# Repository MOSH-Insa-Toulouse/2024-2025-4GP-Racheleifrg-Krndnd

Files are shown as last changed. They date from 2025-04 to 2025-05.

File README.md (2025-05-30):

# 2024-2025-4GP-Racheleifrg-Krndnd

# Graphite-based sensor project

**Students**: Rachele Iffrig, Karine Dandy

Département Génie Physique

INSA Toulouse

## Project Description

The aim of this project is to determine the main characteristics of a low-tech strain sensor, as introduced in the paper “Pencil Drawn Strain Gauges and Chemiresistors on Paper”  by Cheng-Wei Lin, Zhibo Zhao, Jaemyung Kim & Jiaxing Huang, published on Nature in 2014, and to compare them with those of an industrial flex sensor. To do so, both sensors are managed by an Arduino Uno board. On this board we also have an OLED screen in order to display the data, and we navigate through the menus using a rotary encoder. The data are sent to an Android application via a Bluetooth® module.<br> <br>
You can recreate this project from scratch, as we have provided everything — from the PCB design using KiCad, the Arduino code, and the Android app, to the test bench setup used to compare both sensors and create the graphite sensor’s datasheet. 

## Content

In this GitHub repository you will find independent folders for each part of our project.

1) **KiCad**: The KiCad folder contains our project (KiCad-Shield-Uno-FlexSensor) and all the libraries we created and used. It is ready to use, you will only need to download KiCad on your laptop. 
   
2) **Arduino code**: The Arduino folder contains 2 different codes: 
     *code_Flex_OR_graphite_datas_sent_via_bluetooth.ino* and *code_Flex_AND_graphite_datas_sent_via_bluetooth*. Both codes calculate the resistance of the industrial strain gauge sensor as well as the graphite-based one, and are using the rotary encoder to navigate through the different menus displayed on the OLED screen. The difference between the two codes comes with what data we are sending via Bluetooth®. In the first code, at the beginning, the user chooses which sensor’s information they want to plot in the app. The second code sends data from both sensors simultaneously: both resistances are plotted, but with less precision. 
   
3) **Android App**: The Android App folder contains all the information concerning the two apps, made with MIT App Inventor, that are receiving all the data sent via Bluetooth®. With these apps, compatible with Android, you can either plot the resistances of both the flex and graphite sensors simultaneously, or choose to plot only one of them, depending on the code you chose.      

4) **Bench test**: The Bench test folder contains pictures of our graphite-based sensor, and the bench test used.

5) **Results graphite based sensor flex_sensor**: All the results obtained and presented in the sensor's datasheet can be found on the Excel file "Results_graphite-based_sensor_and_flex_sensor". All the calculations made to obtain the relative resistance variation and the deformations are also included in this Excel file. 
   
6) **Sensor project presentation**: The Sensor project presentation folder contains a PowerPoint in which we explain the different steps of our project, the difficulties we faced and the results we obtained.

7) **Datasheet**: The datasheet folder contains the datasheet of our graphite-based sensor. This document describes the main features of the graphite-based sensor, its working principle, its working conditions, and presents the results of the comparison between the flex sensor and graphite-based one. This graphite-based sensor can measure deformations up to 0.006, at room temperature. Higher deformations can break the graphite sensor. 

We found that the hardest pencil (H) was the most sensitive. The same conclusion was also reached by Wei et al. Measurement errors may
have influenced our results, or we may have omitted other unknown factors. Nevertheless, a potential
application for this technology can be observed when using hard pencils. With further material and
experimental modifications, our handmade graphite sensor could be optimized.
 
## Physic behind the low tech strain gauges

This graphite-based sensor works similarly to a strain gauge and can detect mechanical deformations under tension or compression. 
It can measure resistances of the order of the giga-ohm. The working principle relies on the relationship between the average nanoparticle distance and the resistance. 
Due to the granular property of the graphite, under tension, the layer stretches, increasing the distance between the nanoparticles (Figure 1). 
According to percolation theory, the material’s conductivity decreases, while its resistance increases. 
In compression, the distance between the nanoparticles is reduced, and the resistance decreases as more electrical paths are present.

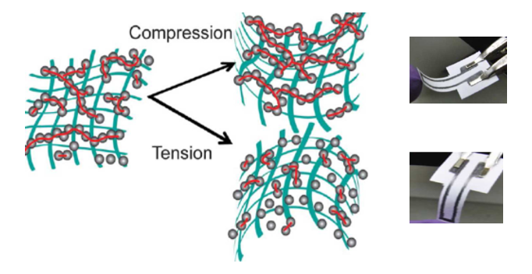
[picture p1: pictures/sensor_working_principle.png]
Imagen1


Figure 1 – Working principle of the graphite-based sensor in compression and tension. Extracted from
“Pencil Drawn Strain Gauges and Chemiresistors on Paper”, by Cheng-Wei et al.

## Necessary components to carry out this project

* 1 graphite-based paper sensor
* 1 flex sensor
* 1 LTC1050 operational amplifier
* 1 MCP41050 digital potentiometer
* 1 KY-040 rotary encoder
* 1 Arduino UNO
* 1 OLED screen
* 1 HC-05 Bluetooth® module
* Resistances: 1kΩ, 10kΩ, 100kΩ, 100kΩ
* Capacitors: 100nF, 100nF, 1µF
* For the test bench: 1 round glass, 1 glue stick, 1 tape, 1 toothpaste cap, 1 liquid correction fluid (Tipp-Ex)

<figure>
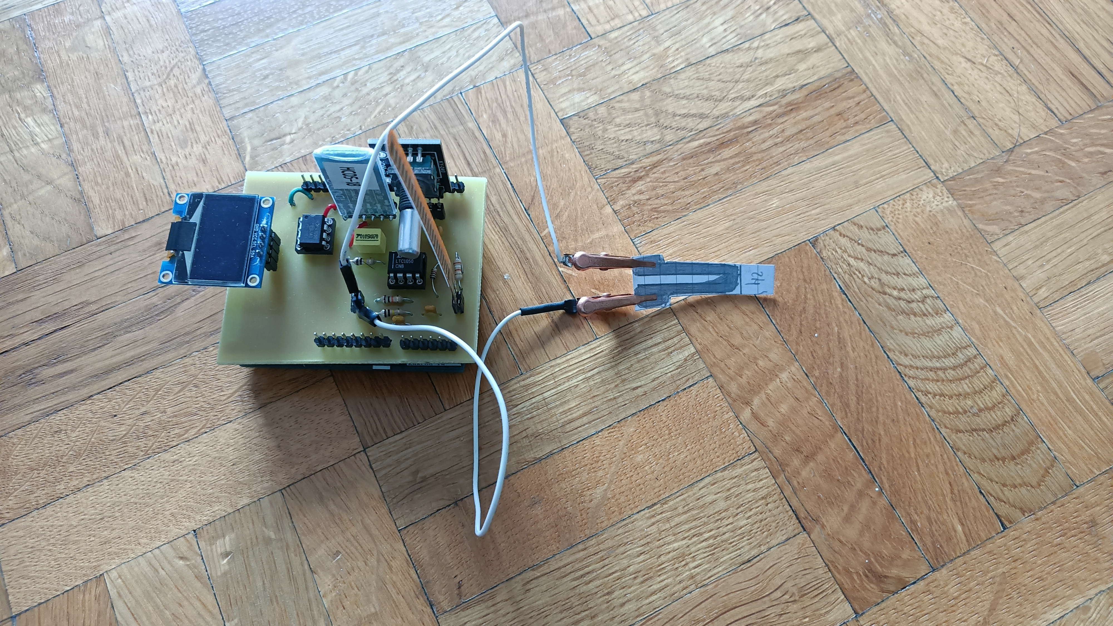
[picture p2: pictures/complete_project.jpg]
complete_project
  
  <figcaption>Figure 2 - Image of the complete project.</figcaption>
</figure>

## How to use

The first step is to create the electrical amplifier circuit and the footprint of the PCB on KiCad. Our complete KiCad project and all the libraries used can be found in the KiCad folder.  

The second step is to order or fabricate the PCB and mount it on an Arduino UNO board. 

By using similar features as our graphite-based sensor (Figure 3), and our Arduino code (available in the Arduino code folder), it is possible to measure a resistance for a given deformation. 

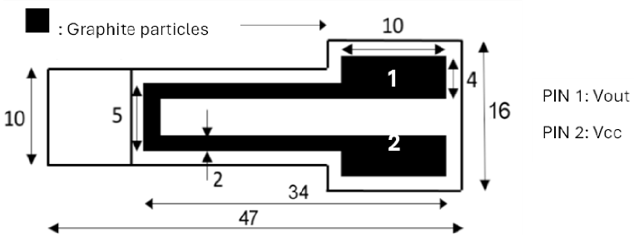
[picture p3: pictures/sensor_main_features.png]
Imagen3


Figure 3 – Representation of our graphite-based sensor. The units are in mm. Extracted from the work
of Paul Besnard and Niels Brun, available on GitHub.

This graphite-based sensor can measure deformations up to 0.006, at room temperature. This sensor can
be made with other paper and graphite pencils to improve sensitivity. We highly recommend
the use of thin papers and harder graphite pencils. 

### Project Assembly

1) Create the PCB using the file *KiCad-Shield-Uno-FlexSensor.kicad_pro* (KiCad/KiCad-Shield-Uno-FlexSensor.kicad_pro) found in the **KiCad** folder. NB: you can also use a breadboard and follow the schematic from the following file: *KiCad-Shield-Uno-FlexSensor.kicad_sch* (KiCad/KiCad-Shield-Uno-FlexSensor.kicad_sch)
2) Solder the components following the PCB and schematic that can be found in the same **KiCad** folder.
3) Connect the PCB to the Arduino, and then connect the Arduino to a PC via USB.
4) Choose one of the two codes from the **Arduino** folder based on your needs.      
5) Once the program is open in the Arduino IDE, select **Arduino Uno** as the board.
6) Run the code.
7) If you chose: *code_Felex_OR_graphite_datas_sent_via_bluetooth.ino* select the data you want to plot on the app, following the instructions that appear on the Serial.

### OLED's Menus
When you upload the code to the Arduino, the OLED screen lights up. On the OLED display, you can access **three different menus**:

1. **Potentiometer Selection Menu**  
   Allows you to choose between **four different potentiometer values**.

2. **Flex Sensor Data Menu**  
   Displays real-time data from the **flex sensor**.

3. **Graphite Sensor Data Menu**  
   Displays real-time data from the **graphite sensor**.<br> <br>
To switch between menus, press the rotary encoder. Inside each menu, rotate the encoder to scroll through the available options. To select an option (if applicable), press the rotary encoder's switch.

### Android App
1. **Pair your smartphone with the HC-05 Bluetooth module.** If a code is requested, enter **0000** or **1234**.

2. **Download the `.exe` file to your smartphone** by scanning the **QR code** in the folder of the Android App.

3. **Open the application**
4. **Grant the necessary permissions** to the application so it can detect Bluetooth® devices connected to your Android.This can be done via your phone’s **Bluetooth® or app settings**.

5.  **Click on the Bluetooth® button**.

6. **Select the HC-05 module** from the list of available devices.

7. **Select the potentiometer value** that you previously chose using the **OLED menu** on the Arduino.

8. **If you are using the Flex or Graph app**,select the resistance value you chose at the beginning of the program from the **drop-down menu**.

9. **Start data acquisition** by pressing the **Start** button.

10. **Stop data acquisition** by pressing the **Stop** button.

<figure>
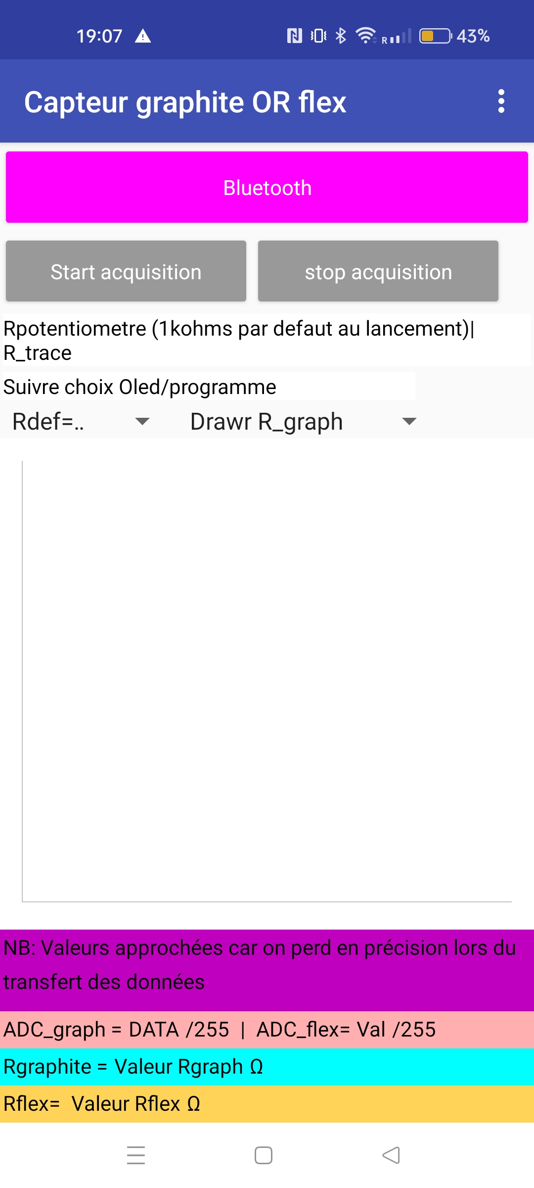
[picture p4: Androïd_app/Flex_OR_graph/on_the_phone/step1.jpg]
app
  
  <figcaption>Figure 4 - Image of the screen when we open the app</figcaption>
</figure>

### Test Bench

To test and compare our graphite-based sensor to a commercial sensor (the flex sensor), we used five objects with different diameters. We then fabricated and tested our graphite-based sensor using three different types of pencils: 2B, H, and HB.   

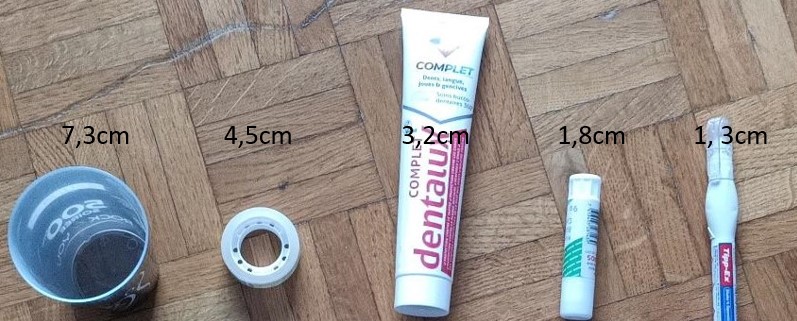
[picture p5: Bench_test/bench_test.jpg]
Imagen5


Figure 5 – Photograph of the objects used with the corresponding diameters during the bench test.

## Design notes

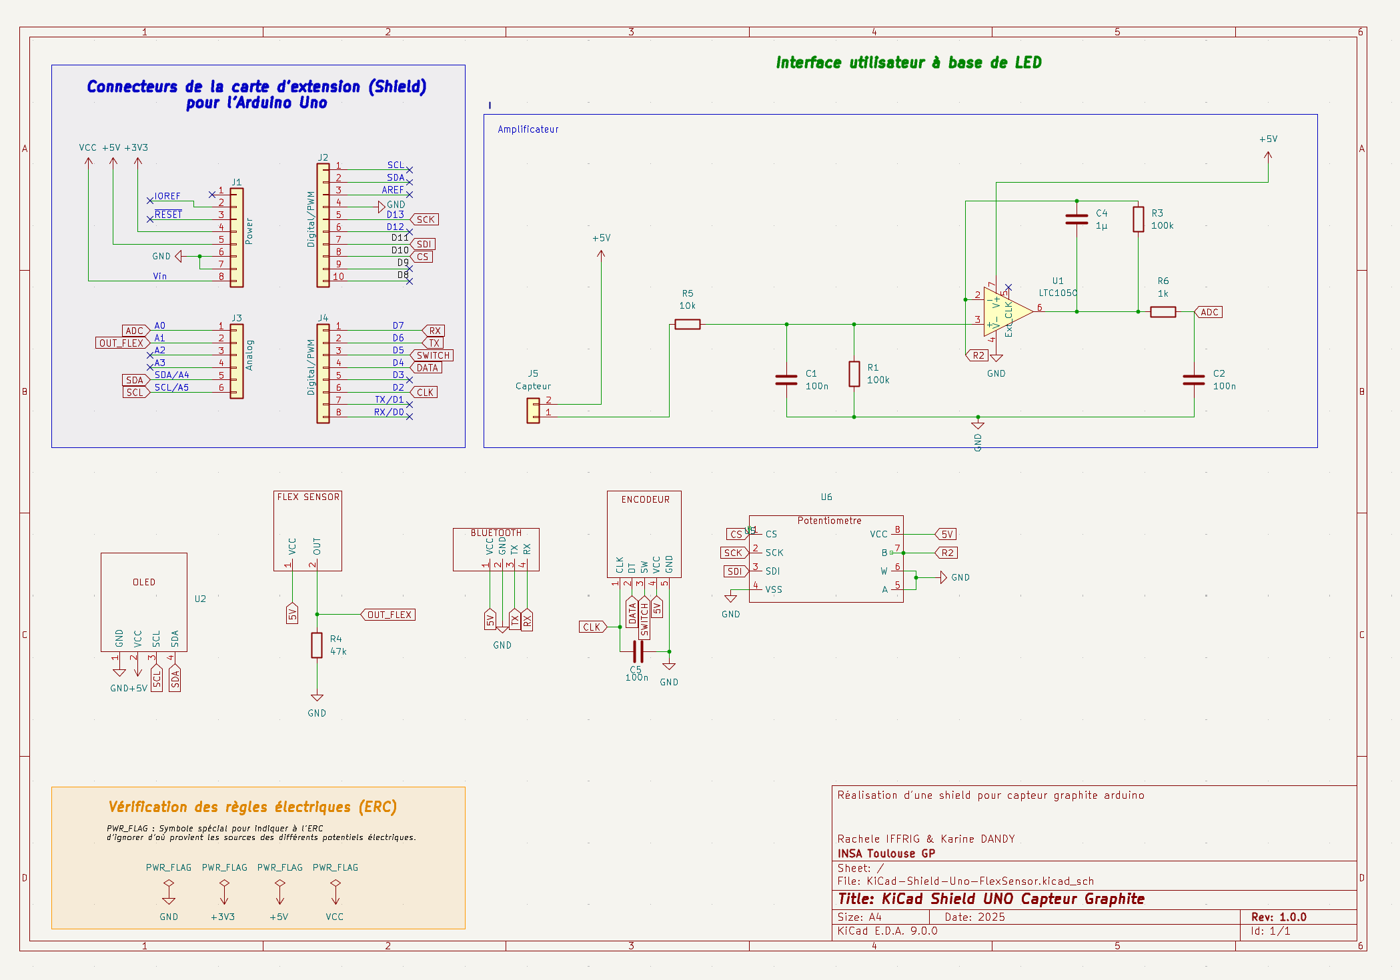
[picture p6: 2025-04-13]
pictures/schematic.png

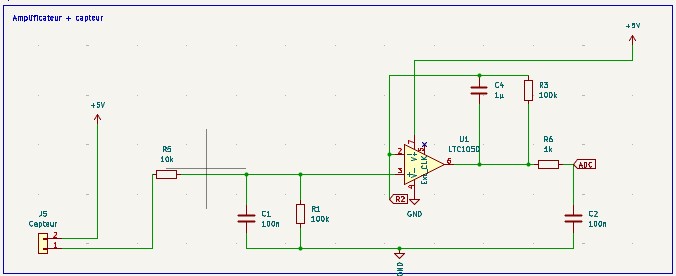
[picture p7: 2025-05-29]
KiCad/PCB_KiCad_models/Amplifier_schematic.jpg

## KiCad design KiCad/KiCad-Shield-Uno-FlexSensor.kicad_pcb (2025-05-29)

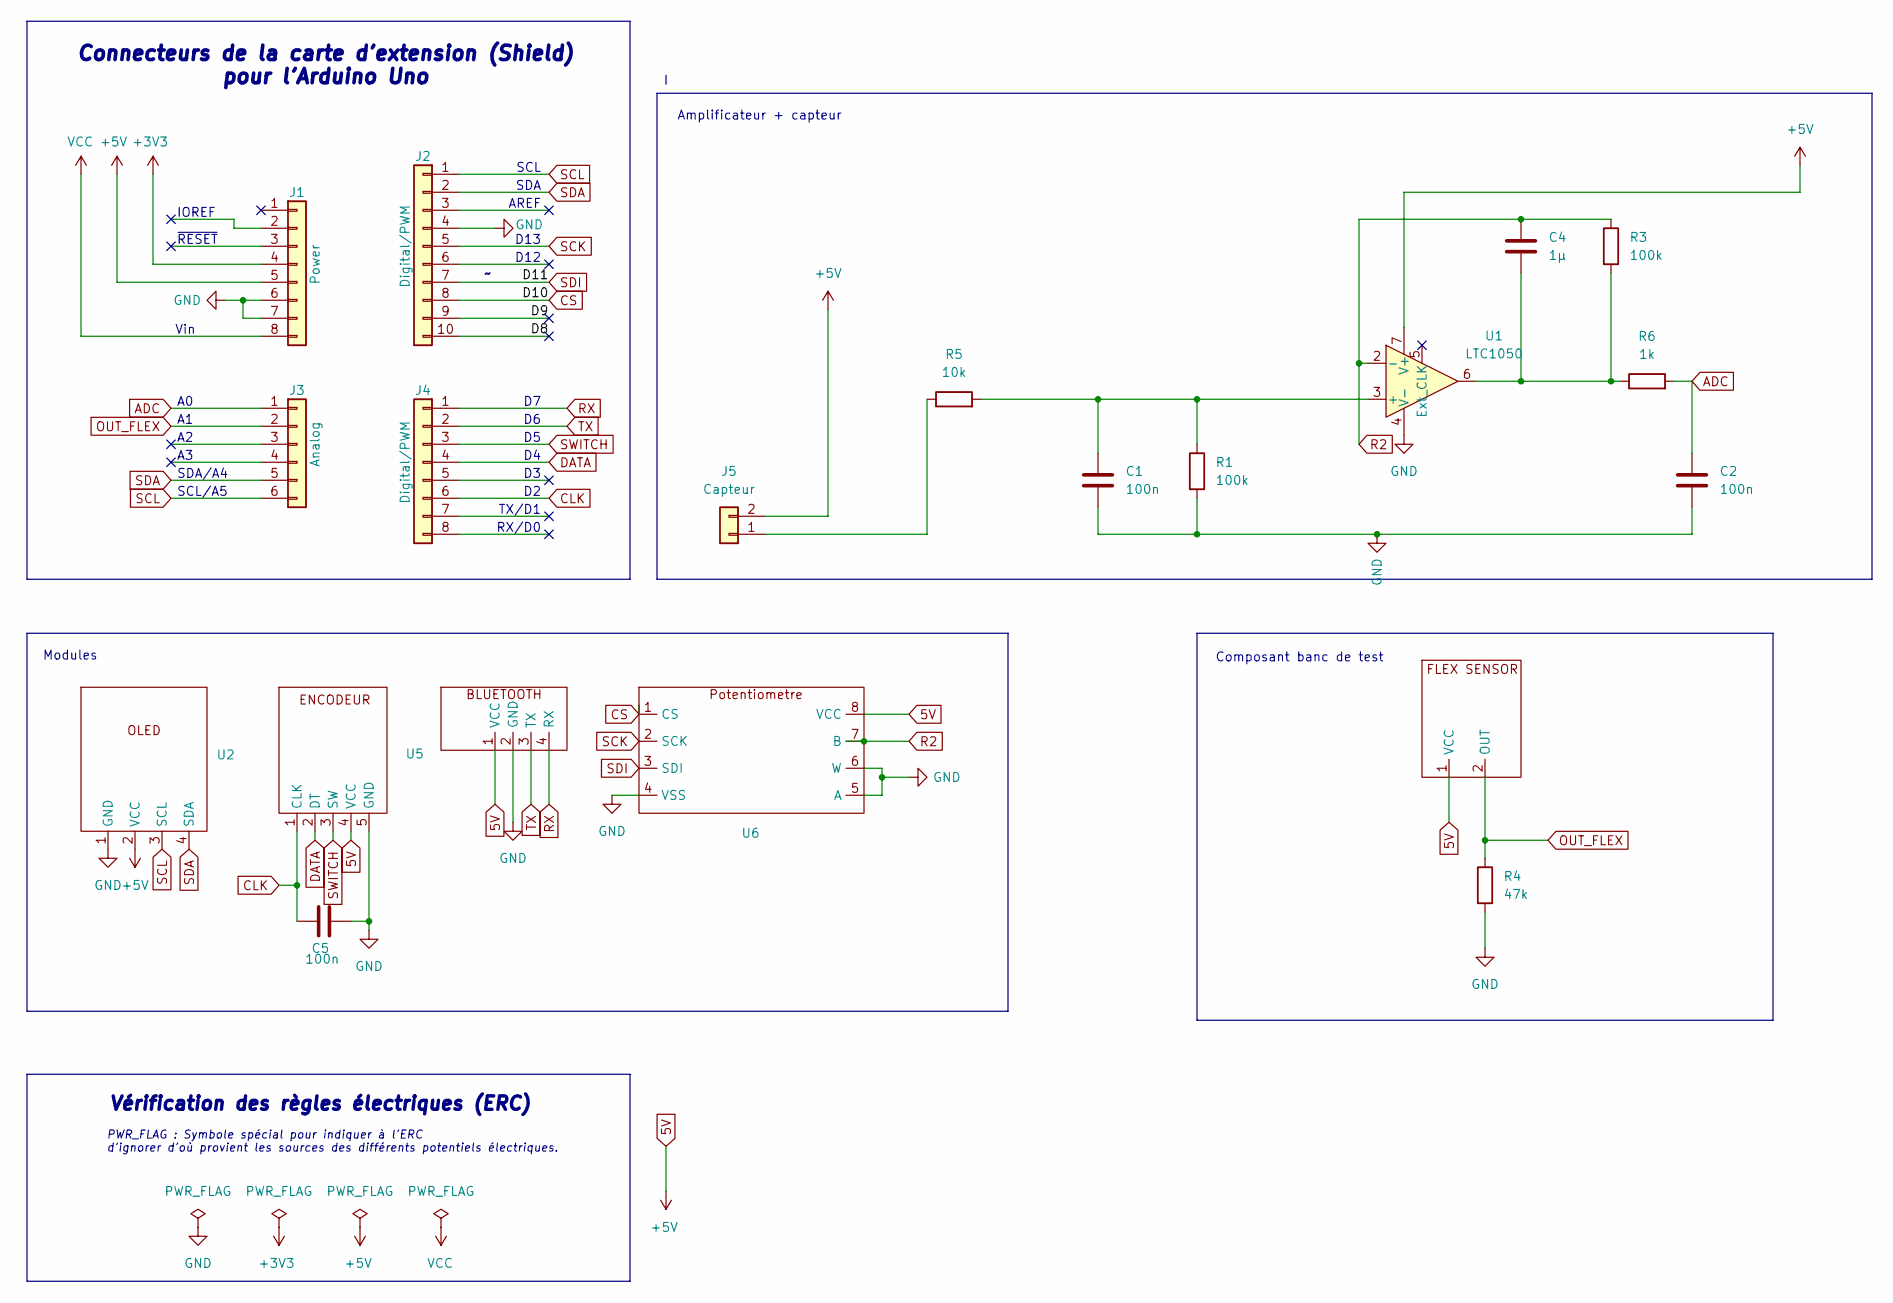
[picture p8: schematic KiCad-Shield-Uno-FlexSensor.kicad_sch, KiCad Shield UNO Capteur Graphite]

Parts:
C1: 100n; C_Disc_D5.0mm_W2.5mm_P5.00mm
C2: 100n; C_Disc_D4.7mm_W2.5mm_P5.00mm
C4: 1µ; C_Rect_L7.0mm_W4.5mm_P5.00mm
C5: 100n; C_Disc_D6.0mm_W2.5mm_P5.00mm
J1: Power; PinSocket_1x08_P2.54mm_Vertical
J2: Digital/PWM; PinSocket_1x10_P2.54mm_Vertical
J3: Analog; PinSocket_1x06_P2.54mm_Vertical
J4: Digital/PWM; PinSocket_1x08_P2.54mm_Vertical
J5: Capteur; PinSocket_1x02_P2.54mm_Vertical
R1, R3: 100k; R_Axial_DIN0207_L6.3mm_D2.5mm_P10.16mm_Horizontal
R4: 47k; R_Axial_DIN0207_L6.3mm_D2.5mm_P5.08mm_Vertical
R5: 10k; R_Axial_DIN0207_L6.3mm_D2.5mm_P10.16mm_Horizontal
R6: 1k; R_Axial_DIN0207_L6.3mm_D2.5mm_P10.16mm_Horizontal
U1: LTC1050
U2: OLED
U3: Flex sensor
U4: bluetooth
U5: ENCODEUR
U6: Potentiometre

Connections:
5V: J1.5, J5.2, U1.7 (V+), U2.2 (VCC), U3.1 (VCC), U4.1 (VCC), U5.4 (VCC), U6.8 (VCC)
+3V3: J1.4
/D8: J2.10
/D9: J2.9
ADC: C2.1, J3.1, R6.2
CLK: C5.1, J4.6, U5.1 (CLK)
CS: J2.8, U6.1 (CS)
DATA: J4.4, U5.2 (DT)
GND: C1.2, C2.2, C5.2, J1.6, J1.7, J2.4, R1.2, R4.2, U1.4 (V-), U2.1 (GND), U4.2 (GND), U5.5 (GND), U6.4 (VSS), U6.5 (A), U6.6 (W)
unnamed: C4.2, R3.2, R6.1, U1.6
unnamed: J5.1, R5.1
unnamed: C1.1, R1.1, R5.2, U1.3 (+)
OUT_FLEX: J3.2, R4.1, U3.2 (OUT)
R2: C4.1, R3.1, U1.2 (-), U6.7 (B)
RX: J4.1, U4.4 (RX)
SCK: J2.5, U6.2 (SCK)
SCL: J2.1, J3.6, U2.3 (SCL)
SDA: J2.2, J3.5, U2.4 (SDA)
SDI: J2.7, U6.3 (SDI)
SWITCH: J4.3, U5.3 (SW)
TX: J4.2, U4.3 (TX)
VCC: J1.8

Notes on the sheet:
Composant banc de test
AREF
SDA/A4
D12
Amplificateur + capteur
~{RESET}
RX/D0
TX/D1
D13
Vin
SDA
Vérification des règles électriques (ERC)
Connecteurs de la carte d'extension (Shield) pour l'Arduino Uno
Modules
SCL/A5
SCL
IOREF
PWR_FLAG : Symbole spécial pour indiquer à l'ERC d'ignorer d'où provient les sources des différents potentiels électriques.

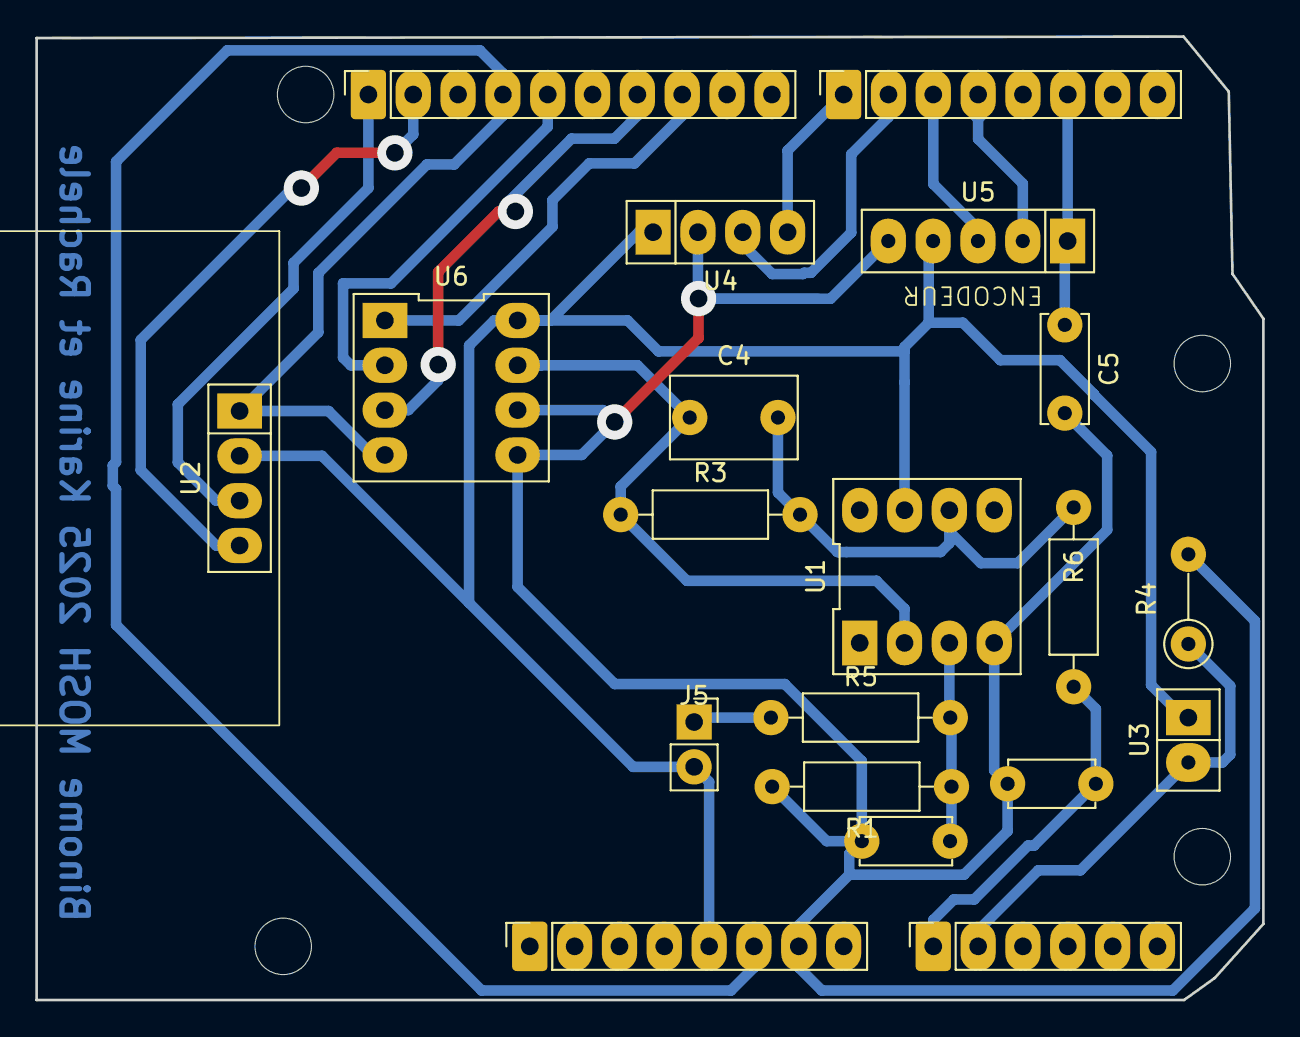
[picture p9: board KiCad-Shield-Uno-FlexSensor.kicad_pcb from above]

Board: 2 copper layers, 69.5 x 54.6 mm, 24 parts (0 on the bottom side), 18 nets.

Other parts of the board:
MH1, MH2, MH3, MH4: MountingHole_3.2mm

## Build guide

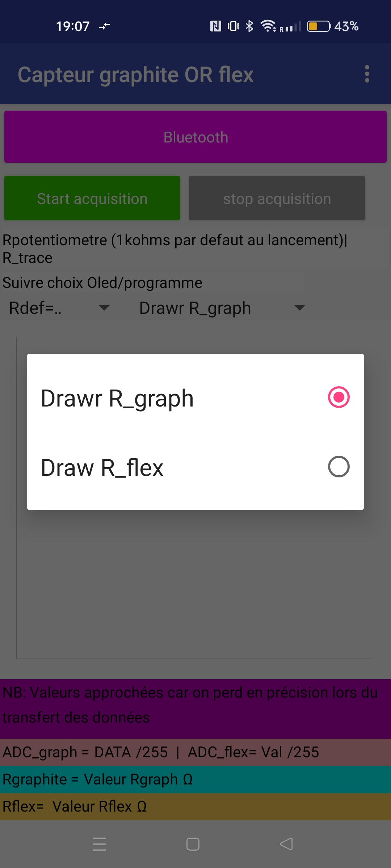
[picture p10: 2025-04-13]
Androïd_app/Flex_OR_graph/on_the_phone/step5_graph.jpg

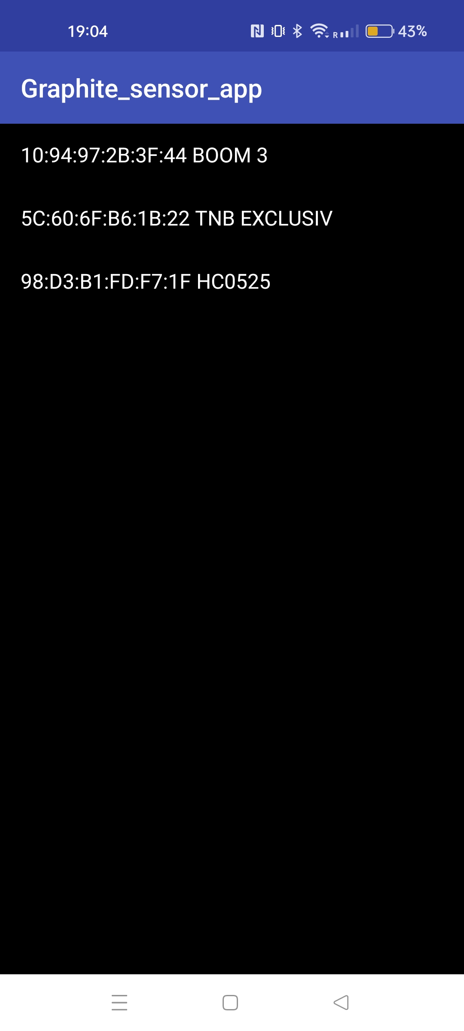
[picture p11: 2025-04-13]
Androïd_app/Flex_OR_graph/on_the_phone/step2.jpg

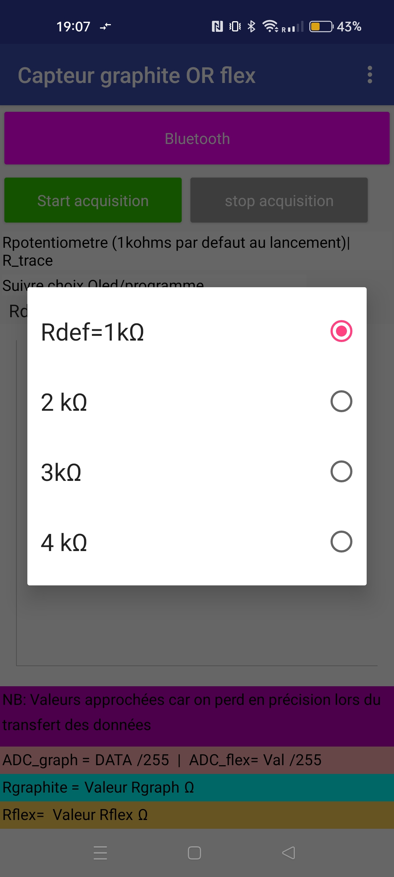
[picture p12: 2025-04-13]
Androïd_app/Flex_OR_graph/on_the_phone/step4.jpg

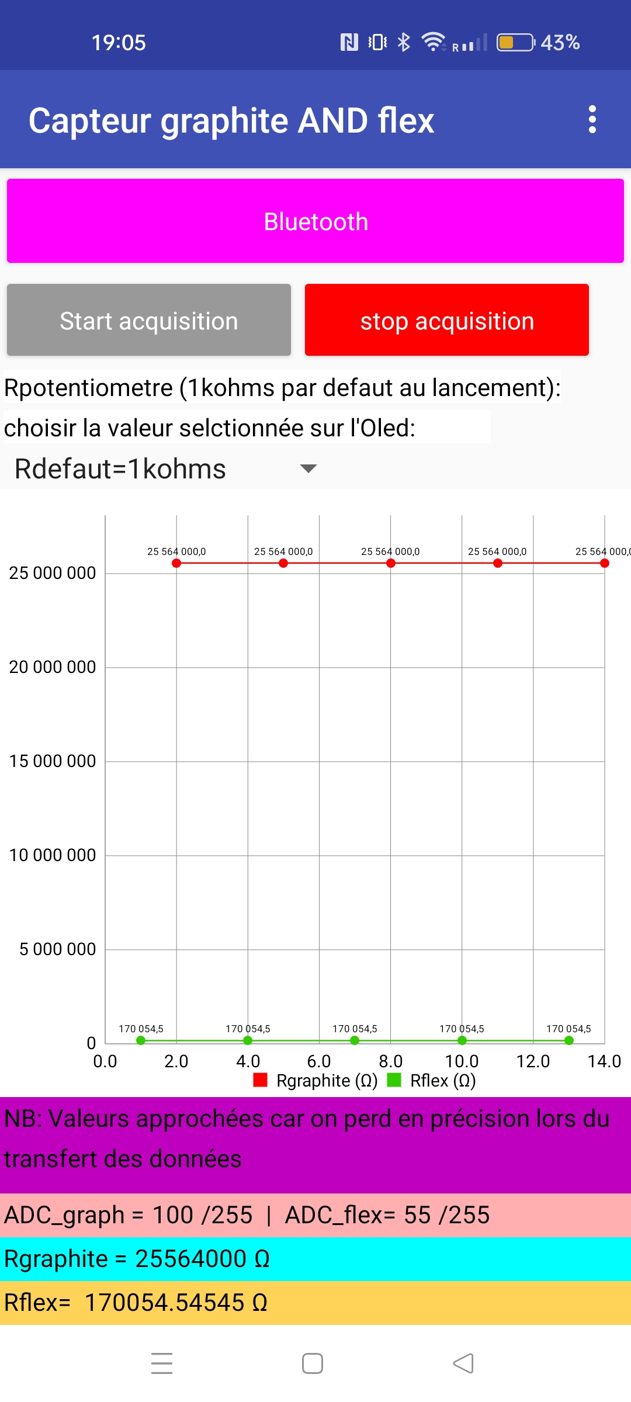
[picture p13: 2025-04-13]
Androïd_app/Flex&graph/on_the_phone/step5.jpg

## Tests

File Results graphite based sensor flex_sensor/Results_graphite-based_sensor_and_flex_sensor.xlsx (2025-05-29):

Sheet: crayon H
 | diametre(cm) | haut/compression | bas/compression
Rblanco | 1.3 | 471852608 | cassé
Rcolle | 1.8 | 199494720 | 1741269248
Rdentifrice | 3.2 | 195626432 | 494987968
Rscotch | 4.5 | 181544656 | 371213504
Rverre | 7.3 | 175237216 | 313554560
Rdefault |  | 169923664 | 169923664

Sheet: crayon 2B
 | diametre(cm) | haut/compression | bas/tension
Rblanco | 1.3 | 22730342 | 48261644
Rcolle | 1.8 | 22424580 | 34597900
Rdentifrice | 3.2 | 22334446 | 27622014
Rscotch | 4.5 | 21351964 | 26343640
Rverre | 7.3 | 20792316 | 23721994
Rdefault |  | 21808402 | 21808402

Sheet: crayon HB
HB |  |  |  | COMPRESSION |  |  | TENSION |  |  | R_courbure(en m) | epaiss. (en m)
 | diametre(cm) | haut/compression | bas/tension | DeltaR | DeltaR/R0 | epsilon | DeltaR | DeltaR/R0 | epsilon | 0.0065 | 0.0002
Rblanco | 1.3 | 19593470 | 35328592 | -1979656 | -0.09176491158 | 0.01538461538 | 13755466 | 0.6376204357 | 0.01538461538 | 0.009
Rcolle | 1.8 | 18832234 | 31912828 | -2740892 | -0.127051221 | 0.01111111111 | 10339702 | 0.4792862193 | 0.01111111111 | 0.016
Rdentifrice | 3.2 | 18428912 | 26694670 | -3144214 | -0.1457467963 | 0.00625 | 5121544 | 0.2374038885 | 0.00625 | 0.0225
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

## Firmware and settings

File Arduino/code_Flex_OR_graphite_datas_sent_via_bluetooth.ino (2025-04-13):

/*  
Complete code for the course: "Projet capteur"
Students: Karine Dandy, Rachele Iffrig
4th year/Genie Physique

Project's description:  
This Arduino code calculates the resistance of an industrial strain gauge sensor as well 
as a graphite-based sensor fabricated following the paper: "Pencil Drawn Gauges and Chemiresistors"
by Cheng-Wei et al.(2014). The resistance values from both sensors are accessible from one of the
several menus displayed on an Oled screen.To go through these menus (flex sensor datas/Graphite sensor datas
/select one of the four potentiometre values proposed) a rotary encoder is used.
 Its switch allows te user to confirm their selection.
At the begining of this code we can chose wether we want to send via bluetooth (by an HC-05 module)
the flex sensor's data or the graphite sensor's data and they are received by an application 
created using MIT App Inventor.
*/


//NB: Please set the potentiometre back to 1kohms at the end,the programme does not do it automatically

// ----- The libraries used:-----------------------------------------------------------------------------------------------------------------
#include <SoftwareSerial.h>
#include <Adafruit_SSD1306.h> // oled
#include <SPI.h> // potentiometre

//Tests to see if the code works -----------------------------------------------------------------------------------------------------------------------

//#define DEBUG_pot
#define DEBUG_sensors_graph
//#define DEBUG_sensors_flex
#define DEB_POT

// ----- important numbers:----------------------------------------------------------------------------------------------------------------
#define baudrate 9600 // Baud rate: the same everywhere

// Bluetooth: need to define the pins for pin mode in the setup-----------------------------------------------------------------------------------------
#define rxPin 7 // Bluetooth reception (TXD Bluetooth) on Arduino pin 7 (Ours: 6)
#define txPin 8 // Bluetooth transmission (RXD Bluetooth) on Arduino pin 8 (Ours: 7)
SoftwareSerial bluetooth_Serial(rxPin ,txPin); // Software serial to send/receive information



// Rotary encodeur----------------------------------------------------------------------------------------------------------------------------------------
#define encoder0PinA  2  //CLK Output A Do not use other pin for clock as we are using interrupt
#define encoder0PinB  4  //DT Output B
#define Switch 5 // Switch connection if available
// To avoid the mechanical rebound effects of the rotary potentiometer, a software filter is used. 
volatile unsigned long lastinterrupttime=0;
const unsigned long debouncetime=60;
bool button_on=0; // state of the switch
static bool lastStateA;
bool stateA;
bool stateB;
volatile unsigned int encoderPos=0;// store if the position of the encodeur increase or decrease

// Potentiometre-----------------------------------------------------------------------------------------------------------------------------------------
//opcodes --> see datasheet MCP4150
#define MCP_NOP 0b00000000 //no operations
#define MCP_WRITE 0b00010001 //send a resitance value between 0 and 255
#define MCP_SHTDWN 0b00100001// Set to high impedance state
const int ssMCPin = 10; // Define the slave select for the digital pot (pin cs)
volatile float Rpotentiometre=1000; // Value we want to assign to the potentiometer, 1kohms by default

//flex sensor-------------------------------------------------------------------------------------------------------------------------------------------
const int flexPin = A1;      // Pin connected to voltage divider output
//What we want to calcultate:
float angle=0.0; //sensor's flexion 
float Rflex=0.0; //flex's resistance
byte ADC_flex_bluetooth=0; //information sent to bluetooth

//graphen sensor----------------------------------------------------------------------------------------------------------------------------------------
float Rgraph_sensor=0.0; // Calculated from the voltage value retrieved by the Arduino
int V_graphsensor=0.0;//given by Arduino
byte Vgraphsensor_bluetooth=0; //information sent to bluetooth

//Oled ------------------------------------------------------------------------------------------------------------------------------------------------
#define nombreDePixelsEnLargeur 128         // OLED screen size, in pixels, at its width
#define nombreDePixelsEnHauteur 64          // OLED screen size, in pixels, at its height
#define brocheResetOLED         -1          //Reset of the OLED shared with the Arduino (hence the value of -1, and not a pin number)
#define adresseI2CecranOLED     0x3C        // Address of 'my' OLED screen on the I2C bus (usually equal to 0x3C or 0x3D)
#define taillecaractere 1  // Character size on the OLED screen
Adafruit_SSD1306 ecranOLED(nombreDePixelsEnLargeur, nombreDePixelsEnHauteur, &Wire, brocheResetOLED); // initialise oled

//Menu Oled
const char *menus[][6] = {
    {"Potentiometre", "Flex Sensor", "Graph Sensor","Menu Principal"},
    {"1 Kohms", "2 Kohms", "3 Kohms", "4 Kohms", "Retour","Potentiometre"},
    {"Resistance", "Angle", "Retour","Flex Sensor"},
    {"V graph", "R graph", "Retour","Graph Sensor"}};
const uint8_t menuSizes[] = {3, 5, 3, 3};// Titles at the end are not counted as part of the menu size
uint8_t menuIndex = 0, menuSelection = 0;


// ----- Function declarations-----

//encodeur
void doEncoder(); // Detects a movement of the rotary encoder and its direction and update the position
void updateEncodeur(); // Update the index according to the menu we are in
void switch_button();//Detects whether the switch has been pressed or not

//bluetooth
void send_bluetooth(float data);// send a byte to the bluetooth

//menu ecran oled
void display_menu();//Displays the menus on the OLED, allows reading sensors values, and selecting potentiometer values  

// Graphene sensor:
void graphen_mesures(); // retrieve the voltage value, calculate and send resistance value to oled + convert and stock ADC value for bluetooth
//flex sensor
void flex_measure(); // retrieve the voltage value, calculate and send resistance + angle values to oled + convert and stock ADC value for bluetooth
//potentiometre
void SPIWrite(uint8_t cmd, uint8_t data, uint8_t ssPin);//sends a command and data to the potentiometre via a slave pin

//choice between plotting Rflex or Rgraphite on the app
bool haschosen=false;
char inputchoice;//choice we make
byte *Rchosen;//pointer pointing to the right value to send over bluetooth
int choice=0;

//----------------------------------------------------------------------------------------------------------------------------------------------------
//----------------------------------------------------------------------------------------------------------------------------------------------------


void setup() { 
  // Initialize the pins and specify their functions, as well as configure the serial communication for data transfer

  //-----Bluetooth-----
  pinMode(rxPin,INPUT);
  pinMode(txPin,OUTPUT);
  bluetooth_Serial.begin(baudrate);

  //----Graphene sensor----
  // Analog pins, so input by default

  //---flex sensor-----
  pinMode(flexPin, INPUT);


    //------Initialize oled------ cf tds
  if(!ecranOLED.begin(SSD1306_SWITCHCAPVCC, adresseI2CecranOLED))
   while(1);                                                // Program stop (infinite loop) if initialization fails
  ecranOLED.clearDisplay();                               // Clear the entire buffer
  ecranOLED.setTextSize(taillecaractere );               // Character size
  ecranOLED.setCursor(0,0);                             // Move the cursor to position (0,0)=>the top-left corner
  ecranOLED.setTextColor(SSD1306_BLACK, SSD1306_WHITE);// Text color and background color
  //------encodeur rotatoir---
  pinMode(encoder0PinA, INPUT_PULLUP); 
  pinMode(encoder0PinB, INPUT_PULLUP); 
  pinMode(Switch,INPUT_PULLUP);
  attachInterrupt(digitalPinToInterrupt(encoder0PinA), doEncoder, CHANGE); // Calls the doencoder function every time a change is detected on pin A

   //-------Potentiometre------
  pinMode (ssMCPin, OUTPUT); //select pin output
  digitalWrite(ssMCPin, HIGH); //SPI chip disabled
  SPI.begin(); 

  Serial.begin (baudrate);
  
} 

//----------------------------------------------------------------------------------------------------------------------------------------------------
//----------------------------------------------------------------------------------------------------------------------------------------------------

void loop(){
  if (haschosen==false){ // we chose wich resitance we want to plot
    Serial.println(F("Choose one of the following option: 1) Draw Rgraphene, 2) Draw Rflex"));
    Serial.println(F("If you want to change the answer run the programm again   "));
    delay(2000);
    if(Serial.available()>0){
      
      inputchoice=Serial.read();
      
      if (inputchoice=='1'){
        Serial.println(F("You chose to draw Rgraphen"));
        choice=1;
        
        haschosen=true;
      }else if (inputchoice=='2'){
        Serial.println(F("You chose to draw Rflex"));
        choice=2;
        haschosen=true;
        
      }else{
        Serial.println(F("You chose a wrong answer,try again"));
      }
    }
  } else {//we already made a choice, we can make measures and use the oled/rotary encoder
    
    flex_measure();
    graphen_mesures();
    updateEncodeur();
    Rchosen=(choice==1)?&Vgraphsensor_bluetooth:&ADC_flex_bluetooth;//pointer pointing on the resistance we chose
    send_bluetooth( *Rchosen);
      #ifdef DEB_POT
    
    Serial.print(F("ADC_chosen ")); 
    Serial.print(*Rchosen); 
    Serial.println(F(" /255")); 
  #endif
    delay(100); //Best delay for the switch

  }
  
  
}

//----------------------------------------------------------------------------------------------------------------------------------------------------
//----------------------------------------------------------------------------------------------------------------------------------------------------

// Detects a movement of the rotary encoder and its direction and update the position
void doEncoder() {
  
    stateA = digitalRead(encoder0PinA);//indicates whether there has been a change in state
    stateB = digitalRead(encoder0PinB);//To determine the direction of rotation
    unsigned long interrupttime=millis();
    if(interrupttime - lastinterrupttime > debouncetime ){//Checks that it is not a bounce
      if (lastStateA != stateA) {  // Change detected
        if (stateB != stateA) {
            encoderPos++;  // Clockwise direction
        } else {
            encoderPos--;  //Counterclockwise direction
        }
        
        lastinterrupttime=interrupttime;//as it is not a rebound
    }

    lastStateA = stateA;//Update the state of the clock
    
    }

    
}

void updateEncodeur(){
      
  if (menuSelection ==0){ //Main menu
  // We convert the position to an index based on the menu size, and turn negative numbers into positive ones
    menuIndex = (encoderPos % menuSizes[0] + menuSizes[0]) % menuSizes[0];
    
  } else if(menuSelection ==1){//Potentiometre menu
    menuIndex=(encoderPos % menuSizes[1] + menuSizes[1])% menuSizes[1];
     }else if(menuSelection ==2){//flex menu
    menuIndex=(encoderPos % menuSizes[2] + menuSizes[2])% menuSizes[2];
    }else if(menuSelection ==3){//graphene menu
    menuIndex=(encoderPos % menuSizes[3] + menuSizes[3] ) % menuSizes[3];
      

  }
  display_menu();//Once we have our positions in the menus, we call the display function for the OLED
  

}

//Detects whether the switch has been pressed or not
void switch_button() {
  static bool lastState = HIGH;//main state of the switch
  bool currentState = digitalRead(Switch);
  if (lastState == HIGH && currentState == LOW) {  // Detection of a button press (falling edge)
    button_on = true;
  } else {
    button_on = false;
  }}


//Displays the menus on the OLED, allows reading sensors values, and selecting potentiometer values 
void display_menu(){
  // Clear the screen at each loop to reset the 'cursor'
    ecranOLED.clearDisplay();
    int memoire=0;//Remember the selected option

   ecranOLED.setCursor(0, 0);  // Cursor position for the first line to write at the correct location
   switch_button();//switch button to change menu

   //MENU PRINCIPAL--------------------------------------------------------------------------------------------------------------------------------------------------------------------------------------
   if (menuSelection ==0){ 
   // TITLE: it cannot be selected
    ecranOLED.setTextColor(SSD1306_WHITE, SSD1306_BLACK); // text color and background color
    ecranOLED.println(menus[menuSelection][3]);

    //Manage the options that can be selected
   for (uint8_t i = 0; i < menuSizes[menuSelection]; i++) {
        // Use of ternary operators because they take up less memory space
        //we change the text and background color of the selected option
        ecranOLED.setTextColor(i == menuIndex ? SSD1306_BLACK : SSD1306_WHITE, i == menuIndex ? SSD1306_WHITE : SSD1306_BLACK);
        ecranOLED.println(menus[menuSelection][i]);
        memoire = (i == menuIndex) ? i : memoire;//memorise the selected option      
        if(button_on){
      menuSelection=memoire+1; //We go to the selected menu. Caution:index pot=0, but the menu selection of the potentiometre is 1=>shift by 1
      encoderPos=0;
      }}}
      
      //MENU POTENTIOMETRE----------------------------------------------------------------------------------------------------------------------------------------------------------------------------------------
      else if(menuSelection ==1){
        // TITLE: it cannot be selected
        ecranOLED.setTextColor(SSD1306_WHITE, SSD1306_BLACK); 
        ecranOLED.println(menus[menuSelection][5]);
 
       //Manage the options that can be selected
       for (uint8_t j = 0; j < menuSizes[menuSelection]; j++) {

          switch_button();
          if (menuIndex == (menuSizes[menuSelection] - 1) && button_on) {
             // If I'm on the return menu and the switch is pressed, I go back to the main menu
            menuSelection = 0;
           encoderPos = 0;
            }else { //we change the text and background color of the selected option
                ecranOLED.setTextColor(j == menuIndex ? SSD1306_BLACK : SSD1306_WHITE, 
                                       j == menuIndex ? SSD1306_WHITE : SSD1306_BLACK);
            
            if(j == menuIndex && button_on){
             //Change the value of the potentiometer to the selected value
              Rpotentiometre=(j+1)*1000;
              //send the right data to the potentiometre=>see the datasheet of MCP4150
              uint8_t data = (j + 1) * 5;
              SPIWrite(MCP_WRITE,data,ssMCPin);
              

              }
            
            
           }

        ecranOLED.println(menus[menuSelection][j]);//display the menu on the Oled
        #ifdef DEBUG_pot
         Serial.print(F("Rpot="));
         Serial.print(Rpotentiometre); 
         Serial.println(F(" Volts"));
        #endif

        
    }
    //Show the current value of the potentiometre
    ecranOLED.setTextColor(SSD1306_WHITE,SSD1306_BLACK );
    ecranOLED.print(F("Rval= "));
            ecranOLED.print(Rpotentiometre);
            ecranOLED.println(F("ohms"));

    

    }else if(menuSelection ==2){ //MENU FLEX----------------------------------------------------------------------------------------------------------------------------------------------

    // TITLE: it cannot be selected
    ecranOLED.setTextColor(SSD1306_WHITE, SSD1306_BLACK); 
    ecranOLED.println(menus[menuSelection][3]);
    
    for (uint8_t k = 0; k < menuSizes[menuSelection]; k++) { //we change the text and background color of the selected option
        
            ecranOLED.setTextColor(k == menuIndex ? SSD1306_BLACK : SSD1306_WHITE, 
                                   k == menuIndex ? SSD1306_WHITE : SSD1306_BLACK);
            ecranOLED.println(menus[menuSelection][k]); // display the menu
            memoire =( menuIndex==k) ? k : memoire;//We keep the information of where the cursor is stored in memory
            button_on=(menuIndex <menuSizes[menuSelection] - 2)?0:button_on;//To ensure that these menus cannot be selected 
        
    }
    //We display the datas based on the cursor position
    if (memoire== 0) {
            ecranOLED.println(F(""));
            ecranOLED.print(F("Rflex= "));
            ecranOLED.print(Rflex);
            ecranOLED.println(F("ohms"));
            
        } else if (memoire == 1) {
          ecranOLED.println(F(""));
          ecranOLED.print(F("Angle="));
          ecranOLED.print(angle);
          ecranOLED.println(F("degres"));
          
        }

    // Button handling and return to the main menu
    if ((menuIndex == (menuSizes[menuSelection] - 1) && button_on)) {
        menuSelection = 0;
        encoderPos = 0;
    }
    

    }else if(menuSelection == 3){ //MENU graphene--------------------------------------------------------------------------------------------------------------------------------------
      // TITLE: it cannot be selected
      int Vgraphen_volts=map(V_graphsensor,0,1024,0,5000);// To be able to display a value in mV on the OLED that makes sense
      ecranOLED.setTextColor(SSD1306_WHITE, SSD1306_BLACK); 
      ecranOLED.println(menus[menuSelection][3]);



      for (uint8_t l = 0; l < menuSizes[menuSelection]; l++) {//we change the text and background color of the selected option
        
            ecranOLED.setTextColor(l == menuIndex ? SSD1306_BLACK : SSD1306_WHITE, 
                                   l == menuIndex ? SSD1306_WHITE : SSD1306_BLACK);
            ecranOLED.println(menus[menuSelection][l]);
            button_on=(menuIndex <menuSizes[menuSelection] - 2)?0:button_on;//To ensure that these menus cannot be selected 
            
            memoire =( menuIndex==l) ? l : memoire;//memorise the selected option
              
            }
            //We display the datas based on the cursor position
            if (memoire== 0) {
            ecranOLED.println("");
            ecranOLED.println(F("Tension graph="));
            ecranOLED.print(Vgraphen_volts); 
            ecranOLED.println(F(" mV"));
            
        } else if (memoire == 1) {
          ecranOLED.println(F(""));
          ecranOLED.println(F("Rgraphene="));
          ecranOLED.print(Rgraph_sensor);
          ecranOLED.println(F(" ohms"));
        }
    // return to the main menu if the switch is on
    if ((menuIndex == (menuSizes[menuSelection] - 1) && button_on)) {
        menuSelection = 0;
        encoderPos = 0;
    }  }
  ecranOLED.display();
}



// Graphene Sensor: Read and send to bluetooth the tension value
void graphen_mesures(){
// We retrieve the voltage values from the sensor after the amplifier 
// We define variables locally, as it takes up less memory space than global definitions
  const float Vcc=5.0;
  const float R5=10000;
  const float R1=100000;
  const float R3=100000;
  
  V_graphsensor=analogRead(A0);
  int V= map(V_graphsensor,0,1024,0,5000); // To convert to 0-5000mV, it's necessary; if we do it directly in volts, 0 => r = infinity
  Rgraph_sensor=abs(((R1*(1+R3/Rpotentiometre)*(Vcc/(V*0.001))-R1-R5)));
  Vgraphsensor_bluetooth=(map(V_graphsensor,0,1024,0,127)<<1)|0x00;//The voltage information is stored in a byte 
  //Serial.print(F("Vgraph_sensor=" ) + String(V_graphsensor) + "Volts"); -->use too much sapce in RAM
// The 'F' allows storing in flash memory instead of RAM  #ifdef DEBUG_sensors_graph
 #ifdef DEBUG_sensors_graph
 Serial.println(V_graphsensor);
  Serial.print(F("ADC_graph=")); 
  Serial.print(Vgraphsensor_bluetooth); 
  Serial.println(F("/255"));
  Serial.print(F("Rgraph_r=")); 
  Serial.print(Rgraph_sensor); 
  Serial.println(F(" ohms"));

  #endif
  
 
}

// send a byte to the bluetooth
void send_bluetooth(byte data){
  
  bluetooth_Serial.write(data);
}

// retrieve the voltage value, calculate and send resistance + angle values to oled + convert and stock ADC value for bluetooth
void flex_measure() {
  
 
  // We define variables locally, as it takes up less memory space than global definitions
  const float VCC = 5;      // voltage at Ardunio 5V line
  const float R_DIV = 47000.0;  // resistor used to create a voltage divider
  const float flatResistance = 25000.0; // resistance when flat
  const float bendResistance = 100000.0;  // resistance at 90 deg
  // Read the ADC, and calculate voltage and resistance from it
  int ADCflex = analogRead(flexPin);
  float Vflex = ADCflex * VCC / 1023.0;
  Rflex = R_DIV * (VCC / Vflex - 1.0);
  ADC_flex_bluetooth=(map(ADCflex,0,1024,0,127)<<1)|0x01;
  // Use the calculated resistance to estimate the sensor's bend angle:
  angle = map(Rflex, flatResistance, bendResistance, 0, 90.0);

  #ifdef DEBUG_sensors_flex
  
  Serial.print(F(" Rflex: ")); 
  Serial.print(Rflex); 
  Serial.println(F(" ohms"));

  /*Serial.print(F("Bend: ")); 
  Serial.print(angle); 
  Serial.println(F(" degrees"));*/
  #endif

  #ifdef DEB_POT
   Serial.print(F("Vflex ")); 
   Serial.print(Vflex); 
   Serial.println(F(" V")); 
   Serial.print(F("ADCflex ")); 
   Serial.print(ADC_flex_bluetooth); 
   Serial.println(F(" ADC")); 
  #endif

}



//sends a command and data to the potentiometre via a slave pin
void SPIWrite(uint8_t cmd, uint8_t data, uint8_t ssPin) // SPI write the command and data to the MCP IC connected to the ssPin
{
  SPI.beginTransaction(SPISettings(14000000, MSBFIRST, SPI_MODE0)); //https://www.arduino.cc/en/Reference/SPISettings
  
  digitalWrite(ssPin, LOW); // SS pin low to select chip
  
  SPI.transfer(cmd);        // Send command code
  SPI.transfer(data);       // Send associated value
  
  digitalWrite(ssPin, HIGH);// SS pin high to de-select chip
  SPI.endTransaction();
}





 
